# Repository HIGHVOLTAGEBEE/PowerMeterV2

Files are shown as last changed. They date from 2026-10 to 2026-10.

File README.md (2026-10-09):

# XT90 Power Meter

Precision high-current power meter with electronic fuse (eFuse) functionality, PWM dimmer and constant-current / constant-power regulation, built around an ESP32-S3 and the INA228 main measuring IC. Designed for continuous currents up to 50 A.

The device measures voltage, current, power and temperature in real time, switches the load through two parallel MOSFETs, and provides a complete web interface plus a 100 Hz JSON serial telemetry stream.

<!-- HERO IMAGE -->
<p align="center">
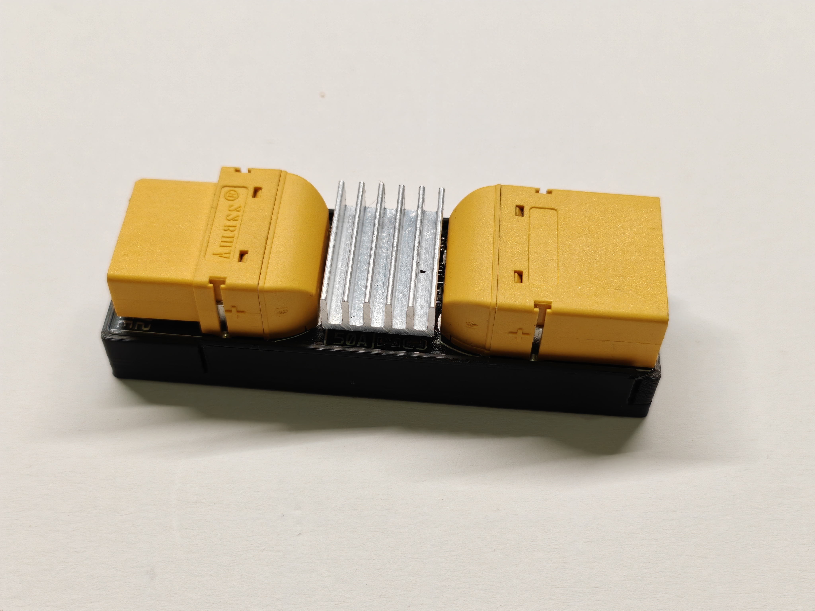
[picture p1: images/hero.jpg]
XT90 Power Meter - assembled device

</p>

---

## Table of Contents

- [Features](#features)
- [Hardware](#hardware)
- [Repository Structure](#repository-structure)
- [About the Software](#about-the-software)
- [Disclaimer](#disclaimer)
- [Getting Started](#getting-started)
- [Usage](#usage)
- [Safety](#safety)
- [Contributing](#contributing)
- [License](#license)

---

## Features

### Live Measurement

- 100 Hz sensor sampling (INA228, 4x averaging, ~550 Hz internal conversion)
- WebSocket live stream at ~77 Hz
- Voltage, current, power and die temperature
- Energy counter (Wh), uptime, peak and minimum values
- Embedded live chart with zoom controls, freeze mode and PNG export

### Electronic Fuse (eFuse)

- Limits: max current, max voltage, min voltage, max temperature
- Configurable trip delay (software time-based fuse)
- Trip report with fault reason, fault values and output runtime before the trip
- Reset via web interface, serial console, or long-press of the user/boot button

### PWM Dimmer

- 10-bit PWM output, frequency configurable from 100 Hz to 30 kHz
- Smooth gauge and live slider in the web interface
- Closed-loop regulators: optinal constant current (CC) and constant power (CP) via P-controller

### Data Logger

- CSV logging to SPIFFS, up to ~65,000 entries
- Log interval configurable from 0.1 s to 3600 s
- Every entry carries the min/peak values recorded during its interval
- Progressive browser-based Excel/CSV export with progress indicator
- Restart events are written into the log

### Calibration

- Browser-based two-step calibration wizard (reference value vs. raw value)
- Separate calibration factors for voltage and current, stored in flash

### System

- Self-hosted WiFi access point (configurable SSID/password)
- mDNS (`meter.local`) when enabled
- IIR smoothing filters for voltage and current
- Configurable status LED (brightness, on/off), boot button enable
- Default-output and auto-logging behavior on boot
- Full settings persistence in flash with CRC16 validation
- UI languages: German / English

---

## Hardware

<p align="center">
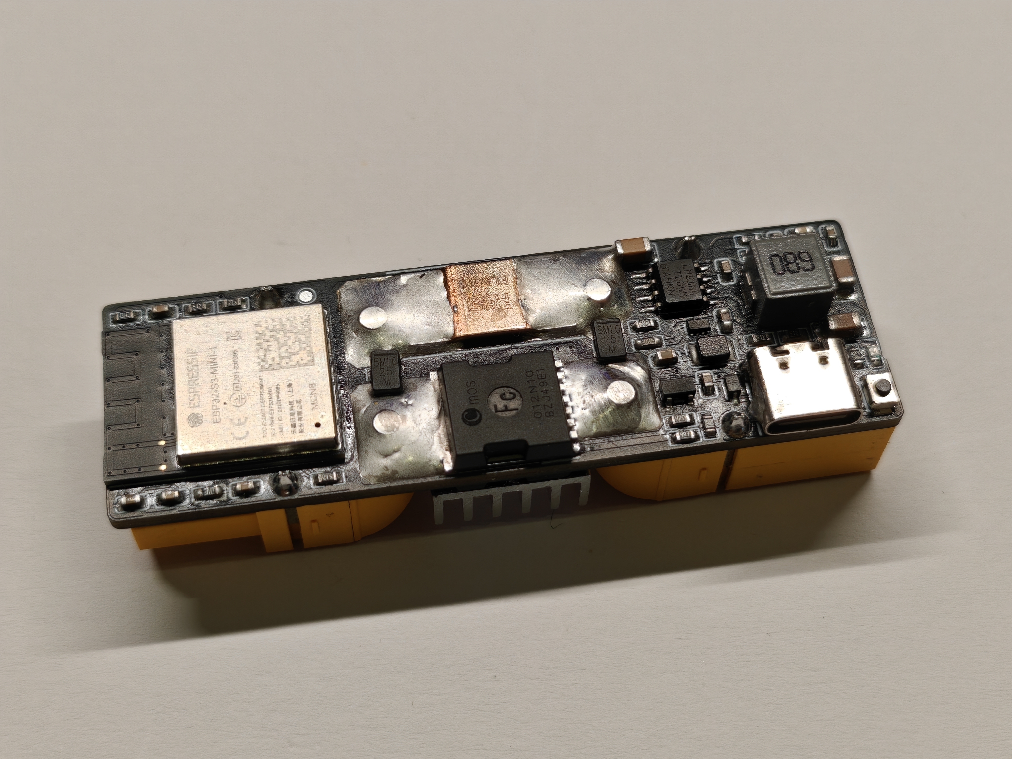
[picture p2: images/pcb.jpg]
XT90 Power Meter - assembled pcb

</p>

### Overview

| Component | Part | Function |
| --- | --- | --- |
| Microcontroller | ESP32-S3-MINI-1-N8 | WiFi AP, web server, control |
| Measurement IC  | INA228 (TI, VSSOP-10) | 20-bit shunt monitor, I2C |
| Shunt | 0.5 mOhm (5930 package) | Current sensing up to 50 A |
| Power MOSFETs | 2x CMSL012N10 (TOLL) | Load switch |
| Gate driver | UCC27517A (SOT-23-5) | MOSFET gate drive |
| Buck 12 V | LM5164 (SO-8) | Input supply from VIN |
| Buck 3.3 V | TPS629206 (SOT-583) | MCU / sensor supply |

### Pinout (ESP32-S3)

| Pin | Function |
| --- | --- |
| GPIO 0 | Boot button (active low) |
| GPIO 4 | PWM output (dimmer, 10-bit) |
| GPIO 5 | Status LED (PWM) |
| GPIO 8 / GPIO 9 | I2C SDA / SCL (INA228, 400 kHz) |
| GPIO 10 | INA228 ALERT (reserved, currently unused) |

### Schematic, PCB and Assembly

All hardware files are located in the `PCB/` folder:

| Document | File |
| --- | --- |
| Schematic | `PCB/schematic.pdf` |
| Gerber files | `PCB/gerber.zip` (RS-274X) |
| Bill of materials | `PCB/bom.xlsx` (LCSC part numbers included) |
| Pick and place | `PCB/pick.xlsx` |
| 3D model of the PCB | `PCB/3d_model.step` |

### Enclosure

<!-- CASE IMAGE -->
<p align="center">
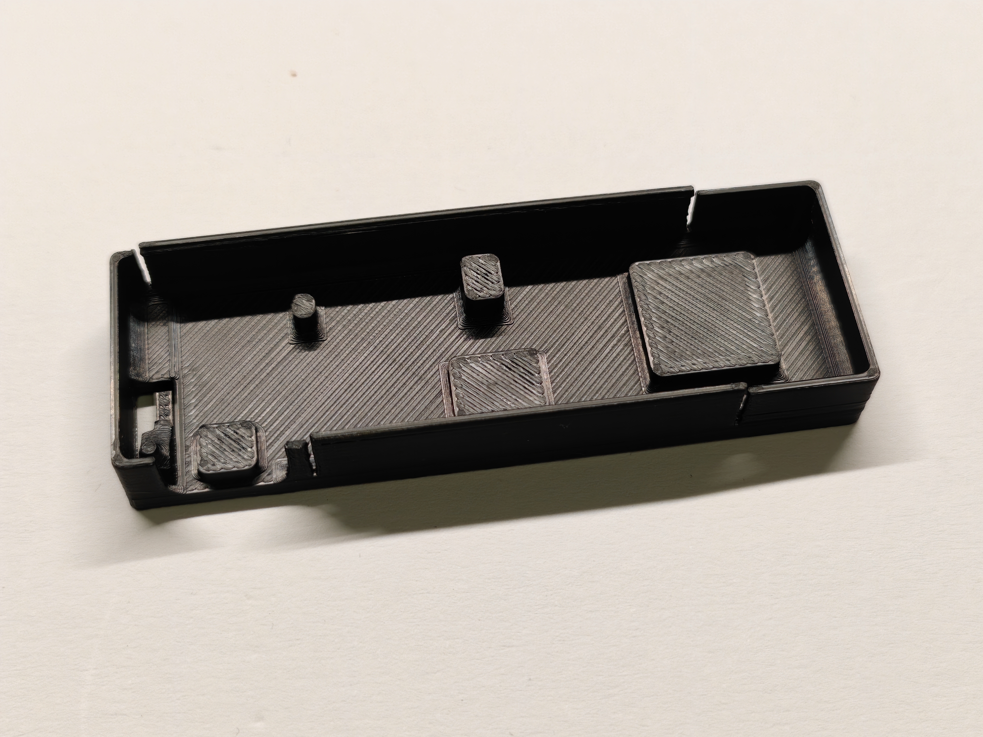
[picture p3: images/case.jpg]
XT90 Power Meter - Case

</p>

The 3D-printable enclosure is included as a 3MF file directly in the repository root. It snaps onto the PCB edge without screws and provides openings for both XT90 connectors, the USB-C port and the status LED.

| Property | Recommendation |
| --- | --- |
| File | `Case.3mf` (repository root)  |
| Material | PETG |
| Print settings | Extra Fine 0.08mm No Supports |

---

## Repository Structure

```javascript
.
├── Firmware/                   PlatformIO project (ESP32-S3)
│   ├── platformio.ini          Board config, libraries, build flags
│   ├── partitions_8mb.csv      Flash layout (3.5 MB app + 4 MB SPIFFS)
│   ├── main.cpp                Main program
│   └── include/                All firmware modules
│       ├── INA228Wrapper.*     Sensor driver, smoothing, calibration
│       ├── WebInterface.*      HTTP/WebSocket, eFuse logic, CC/CP regulator
│       ├── WebPages.*          Web UI pages
│       ├── DataLogger.*        SPIFFS CSV logging, chunked export
│       ├── Settings.*          EEPROM persistence with CRC16
│       ├── StatusLED.*         LED modes (on / breathing / eFuse blink)
│       └── SerialConsole.*     JSON command line, 100 Hz telemetry
├── PCB/
│   ├── gerber.zip              Gerber files (RS-274X)
│   ├── schematic.pdf           Schematic
│   ├── bom.xlsx                Bill of materials (LCSC part numbers)
│   ├── pick.xlsx               Pick and place data
│   └── 3d_model.step           3D model of the PCB
├── Case.3mf                    3D-printable snap-on enclosure
├── images/                     Photos and screenshots
├── LICENSE                     GNU AGPL v3
├── README.md
└── SETUP.md                    Detailed build and setup guide
```

---

## About the Software

A significant portion of the firmware was created with the assistance of generative AI tools. It works and has been tested on real hardware, but it should be seen as a solid starting point rather than a finished, peer-reviewed product.

I am not a software developer, and I am happy about every contribution. If you are a software developer and spot weak spots, structural problems or potential bugs or simply have ideas for new features, please open an issue or a pull request.

---

## Disclaimer

**This is a private hobby project.**

There is **no guarantee of functionality** - neither for the hardware nor for the firmware. Everything is provided "as is", without any warranty of any kind. I am not an electrical engineer or a professional software developer.

Use this project **entirely at your own risk**. It has been built and tested to the best of my knowledge, but it is not certified, not safety rated and not intended for any application where failure could cause damage, injury or danger - especially not for safety critical or unattended operation.

If you build and use this device, you are responsible for verifying that it works correctly in your setup and for complying with all applicable regulations.

---

## Getting Started

The firmware is a complete [PlatformIO](https://platformio.org/) project for Visual Studio Code - board settings, library dependencies and the flash partition table are all defined in `platformio.ini`, no manual library installation required.

The short version:

1. Install [Visual Studio Code](https://code.visualstudio.com/) with the [PlatformIO IDE extension](https://platformio.org/platformio-ide).
2. Open the `Firmware/` folder as a PlatformIO project and upload it to the board (Upload button in the PlatformIO toolbar or `pio run --target upload`).
3. Power the board through the XT90 input.
4. Connect to the WiFi access point (default SSID `XT90_PowerMeter`, password `12345678`).
5. Open `http://192.168.4.1` or `http://meter.local` in a browser.

Full details: [SETUP.md](SETUP.md)

---

## Usage

### Web Interface

Connect to the access point and open `http://192.168.4.1` or `http://meter.local` (with mDNS enabled).

| Page | Content |
| --- | --- |
| `/` | Live view: readings, chart, output switch |
| `/logger` | Peaks/minimums, energy, logging control, Excel export |
| `/efuse` | Limits, trip report, reset |
| `/dimmer` | Dimmer slider, CC/CP regulator, gauge |
| `/config` | WiFi, PWM, smoothing, LED, button, logger, language |
| `/calibrate` | Calibration wizard |

### Serial Console

USB-CDC at 2,000,000 baud. Continuous JSON telemetry at 100 Hz and a status frame every 5 s. Commands are sent as JSON lines, for example:

```json
{"cmd":"status"}
{"cmd":"get"}
{"cmd":"set","key":"maxCurrent","value":25}
{"cmd":"output","value":1}
{"cmd":"dimmer","value":50}
{"cmd":"dimmeren","value":1}
{"cmd":"logging","value":1}
{"cmd":"efuse","value":1}
{"cmd":"resetefuse"}
{"cmd":"log"}
{"cmd":"logclear"}
{"cmd":"help"}
```

All available setting keys are listed by `{"cmd":"help"}` and `{"cmd":"get"}`.

### Boot Button

- **Short press:** toggle output
- **Long press (> 2 s):** reset eFuse

**(Currently not very reative)**

---

## Safety

- The device is designed for high currents. At 50 A, the 0.5 mOhm shunt dissipates up to 1.25 W + Mosfet heat dissipation.
- The eFuse is a software protection function and does not replace a certified fuse.
- Respect the MOSFET voltage and current ratings and provide sufficient cooling for continuous load.
- The output MOSFETs switch on the low side. When the output is off, VOUT remains connected to VIN through the load path.

---

## Contributing

Contributions of any kind are welcome - whether it is:

- bug reports and bug fixes
- code quality and structural improvements
- ideas for new features
- documentation improvements
- hardware feedback from your own build

Please open an issue first for larger changes so we can discuss the direction.

---

## License

This project is licensed under the **GNU Affero General Public License v3.0** - see the [LICENSE](LICENSE) file for details. The hardware design files are provided for reference and manufacturing.

The firmware is distributed in the hope that it will be useful, but WITHOUT ANY WARRANTY. If you run a modified version of this firmware on a network server, the AGPL requires you to make the corresponding source code available to users interacting with it.

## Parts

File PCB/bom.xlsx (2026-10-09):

No. | Quantity | Comment | Designator | Footprint | Value | Manufacturer Part | Manufacturer | Supplier Part | Supplier
1 | 1 | 2.2uF | C1 | C1206 | 2.2uF | FS31X225K101EPG | PSA(信昌电陶) | C1021612 | LCSC
2 | 2 | 22uF | C2,C3 | C1206 | 22uF | FS31X226M160EPG | PSA(信昌电陶) | C3036083 | LCSC
3 | 1 | 3.3nF | C4 | C0603 | 3.3nF | CC0603KRX7R9BB332 | YAGEO(国巨) | C107088 | LCSC
4 | 1 | 2.2nF | C5 | C0603 | 2.2nF | FCC0603B222K500CT | FOJAN(富捷) | C5137562 | LCSC
5 | 1 | 56pF | C6 | C0603 | 56pF | 0603CG560J500NT | FH(风华) | C1676 | LCSC
6 | 5 | 100nF | C7,C11,C12,C14,C16 | C0603 | 100nF | CL10B104KB8NFNC | SAMSUNG(三星) | C346191 | LCSC
7 | 2 | 22uF | C8,C13 | C0603 | 22uF | CL10A226MQ8NRNC | SAMSUNG(三星) | C59461 | LCSC
8 | 2 | 4.7uF | C9,C17 | C0603 | 4.7uF | CL10A475KO8NNNC | SAMSUNG(三星) | C19666 | LCSC
9 | 1 | 100nF | C10 | C0603 | 100nF | CL10B104KC8NNNC | SAMSUNG(三星) | C15725 | LCSC
10 | 1 | 1uF | C15 | C0603 | 1uF | CL10B105KA8NNNC | SAMSUNG(三星) | C29936 | LCSC
11 | 1 | XT90PW-M.G.Y | CN1 | CONN-TH_XT90PW-M.G.Y |  | XT90PW-M.G.Y | AMASS(艾迈斯) | C3040689 | LCSC
12 | 1 | CUS08F30,H3F | D2 | SOD-323F_L1.7-W1.3-LS2.5-RD |  | CUS08F30,H3F | TOSHIBA(东芝) | C150183 | LCSC
13 | 1 | 68uH | L1 | IND-SMD_L7.1-W6.6_H5.0 | 68uH | PSPMAA0605H-680M-IGF | PROD(谱罗德) | C2983094 | LCSC
14 | 1 | 2.2uH | L4 | L1008 | 2.2uH | APH252012C2R2MP01 | APV(爱普微) | C42455362 | LCSC
15 | 1 | YLED0603O | LED1 | LED0603-FD |  | YLED0603O | YONGYUTAI(永裕泰) | C19273153 | LCSC
16 | 2 | CMSL012N10 | Q1,Q2 | TOLL-8_L10.4-W9.9-P1.20-LS11.7-BL_2 |  | CMSL012N10 | Cmos(广东场效应半导体) | C53310613 | LCSC
17 | 2 | 442kΩ | R1,R4 | R0603 | 442kΩ | RT0603BRD07442KL | YAGEO(国巨) | C861407 | LCSC
18 | 1 | 49.9kΩ | R2 | R0603 | 49.9kΩ | RT0603BRD0749K9L | YAGEO(国巨) | C705780 | LCSC
19 | 1 | 100kΩ | R3 | R0603 | 100kΩ | FRC0603J104 TS | FOJAN(富捷) | C2907088 | LCSC
20 | 2 | 4.7Ω | R5,R6 | R0603 | 4.7Ω | SR0603FR-7W4R7L | YAGEO(国巨) | C326830 | LCSC
21 | 3 | 10kΩ | R7,R8,R10 | R0603 | 10kΩ | FRC0603J103 TS | FOJAN(富捷) | C2930027 | LCSC
22 | 1 | 124kΩ | R9 | R0603 | 124kΩ | TC0325B1243T5F | UNI-ROYAL(厚声) | C7431036 | LCSC
23 | 6 | 5.1kΩ | R11,R12,R13,R16,R17,R18 | R0603 | 5.1kΩ | RC0603FR-075K1L | YAGEO(国巨) | C105580 | LCSC
24 | 2 | 10Ω | R14,R15 | R0603 | 10Ω | 0603WAJ0100T5E | UNI-ROYAL(厚声) | C25202 | LCSC
25 | 1 | TS-064SA-017250-D4-P | SW3 | SW-SMD_L3.0-W2.5-P3.40-LS4.0-L |  | TS-064SA-017250-D4-P | Zhongdi(众迪) | C55067267 | LCSC
26 | 1 | TP | TP2 | TESTPOINT-TH_BD3.2_1 |  | TP |  | C9900007422 | LCSC
27 | 1 | INA228AQDGSRQ1 | U1 | VSSOP-10_L3.0-W3.0-P0.50-LS4.9-BL |  | INA228AQDGSRQ1 | TI(德州仪器) | C5214669 | LCSC
28 | 1 | 0.5mΩ | U2 | R5930 | 0.5mΩ | PEWM5930DL500K9 | RESI(开步睿思) | C22446542 | LCSC
29 | 1 | XT90PW-F30.G.Y | U3 | CONN-TH_XT90PW-M |  | XT90PW-F30.G.Y | AMASS(艾迈斯) | C3040690 | LCSC
30 | 1 | LM5164DDAR | U4 | SO-8_L4.9-W3.9-P1.27-LS6.0-BL-EP |  | LM5164DDAR | TI(德州仪器) | C477928 | LCSC
31 | 1 | TPS629206DRLR | U6 | SOT-583-8_L2.1-W1.2-P0.50-LS1.6-BL |  | TPS629206DRLR | TI(德州仪器) | C5219292 | LCSC
32 | 1 | 2.4GHz | U7 | BULETM-SMD_ESP32-S3-MINI-1-N8 | 2.4GHz | ESP32-S3-MINI-1-N8 | ESPRESSIF(乐鑫) | C2913206 | LCSC
33 | 2 | VSSAF5M10-M3/H | U8,U9 | SMA_L4.3-W2.6-LS5.2-RD |  | VSSAF5M10-M3/H | VISHAY(威世) | C5241914 | LCSC
34 | 1 | UCC27517ADBVR | U10 | SOT-23-5_L2.9-W1.6-P0.95-LS2.8-BL |  | UCC27517ADBVR | TI(德州仪器) | C2653784 | LCSC
35 | 1 | TYPE-C 16PIN 2MD(073) | USB2 | USB-C-SMD_TYPE-C-16PIN-2MD-073 |  | TYPE-C 16PIN 2MD(073) | SHOU HAN(首韩) | C2765186 | LCSC

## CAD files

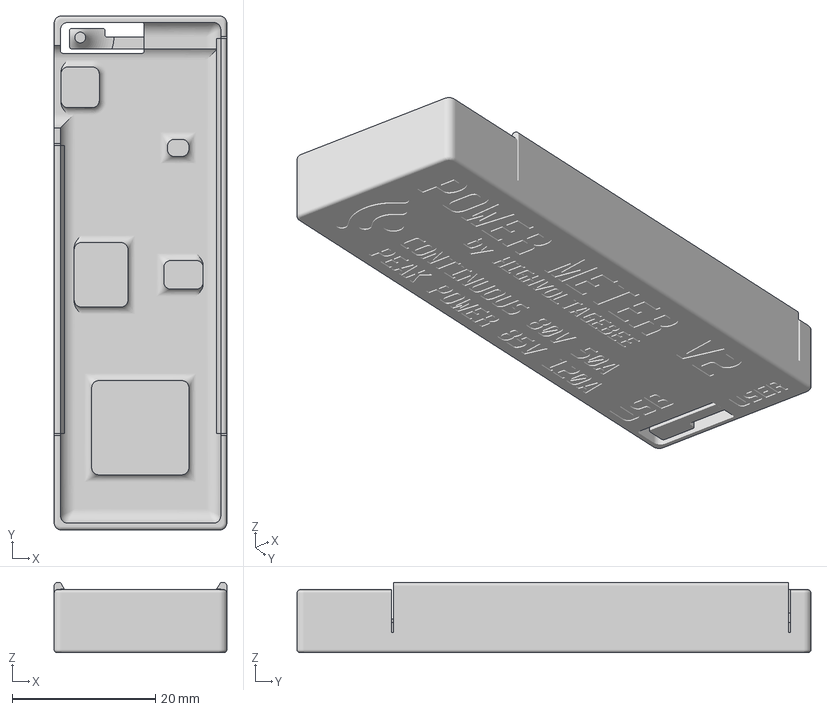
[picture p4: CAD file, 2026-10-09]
Case.3mf
24.1 x 71.7 x 9.79 mm

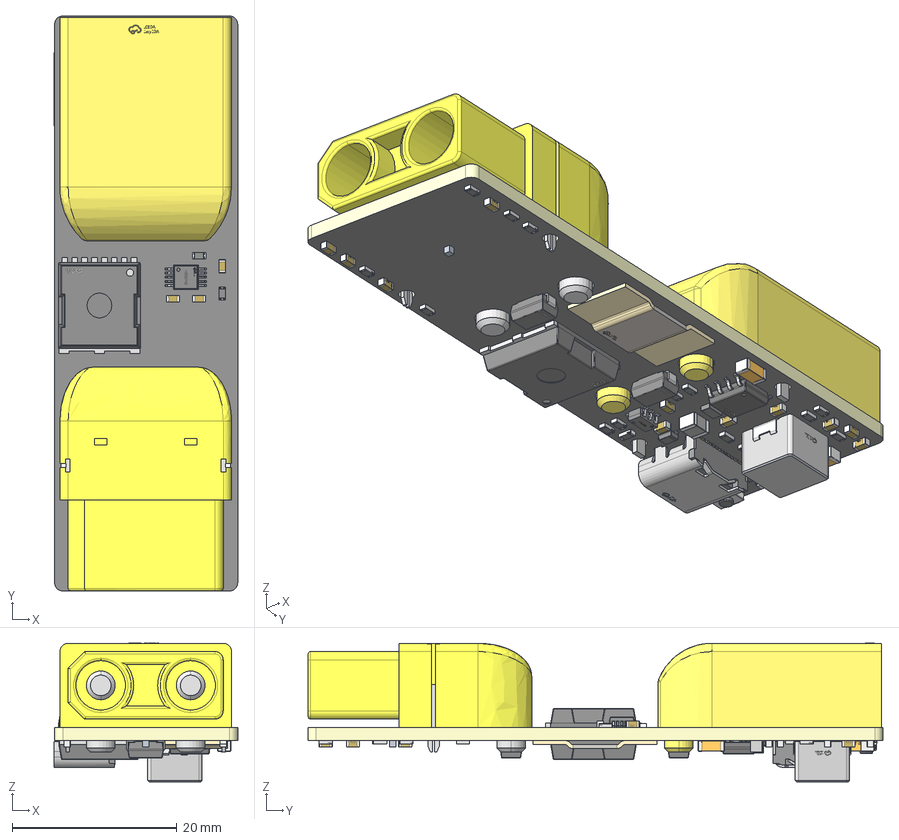
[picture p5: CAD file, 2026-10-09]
PCB/3d_model.step
22.2 x 69.7 x 16.8 mm
Board~EgBH
TopCopper~EgBH
BottomCopper~EgBH
TopSilkscreen~EgBH
BottomSilkscreen~EgBH
TopFpcStiffener~EgBH
BottomFpcStiffener~EgBH
BULETM-SMD_ESP32-S3-MINI-1-N8~BULETM-SMD_ESP32-S3-MINI-1-N8~EgBH
R5930~R5930~EgBH
L1008~L1008~EgBH
CONN-TH_XT90PW-M~CONN-TH_XT90PW-M~EgBH
R0603~R0603~EgBH x 18
CONN-TH_XT90PW-M.G.Y~CONN-TH_XT90PW-M.G.Y~EgBH
C0603~C0603_L1.6-W0.8-H0.8~EgBH x 14
IND-SMD_L7.1-W6.6_H5.0~IND-SMD_L7.1-W6.6-H5.0~EgBH
TOLL-8_L10.4-W9.9-P1.20-LS11.7-BL_2~TOLL-8_L10.4-W9.9-P1.20-LS11.7-BL_ 2~EgBH x 2
LED0603-FD~LED0603_Inf~EgBH
SOT-583-8_L2.1-W1.2-P0.50-LS1.6-BL~SOT-583-8_ L2.1-W1.2-P0.50-LS1.6-BL~EgBH
SW-SMD_L3.0-W2.5-P3.40-LS4.0-L~SW-SMD_ L3.0-W2.5-H1.6-P3.40-LS4.0-L~EgBH
SMA_L4.3-W2.6-LS5.2-RD~SMA_L4.3-W2.6-LS5.2-RD~EgBH x 2
C1206~C1206_L3.2-W1.6-H1.3~EgBH x 3
USB-C-SMD_TYPE-C-16PIN-2MD-073~USB-C-SMD_TYPE-C-6PIN-2MD-073~EgBH
SOD-323F_L1.7-W1.3-LS2.5-RD~SOD-323F_L1.7-W1.3-LS2.5-RD~EgBH
SO-8_L4.9-W3.9-P1.27-LS6.0-BL-EP~SO-8_L4.9-W3.9-H1.5-LS5.9-P1.27~EgBH
SOT-23-5_L2.9-W1.6-P0.95-LS2.8-BL~SOT-23-5_ L2.9-W1.6-P0.95-LS2.8-BL~EgBH
VSSOP-10_L3.0-W3.0-P0.50-LS4.9-BL~VSSOP-10_ L3.0-W3.0-H1.1-LS4.9-P0.50~EgBH

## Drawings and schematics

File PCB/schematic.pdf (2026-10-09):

IO48 30 IO35 31 IO36 32 IO37 33 IO38 34 IO39 35 IO40 36 IO41 37 IO42 38 TXD0 39 RXD0 40 IO45 41 GND 42 GND 43 IO46 44 EN 45 GND 46 GND 47 GND 48 GND 49 GND 50 GND 51 GND 52 GND 53 GND 54 GND 55 GND 56 GND 57 GND 58 GND 59 GND 60 GND U72.4GHz

# Mosfets

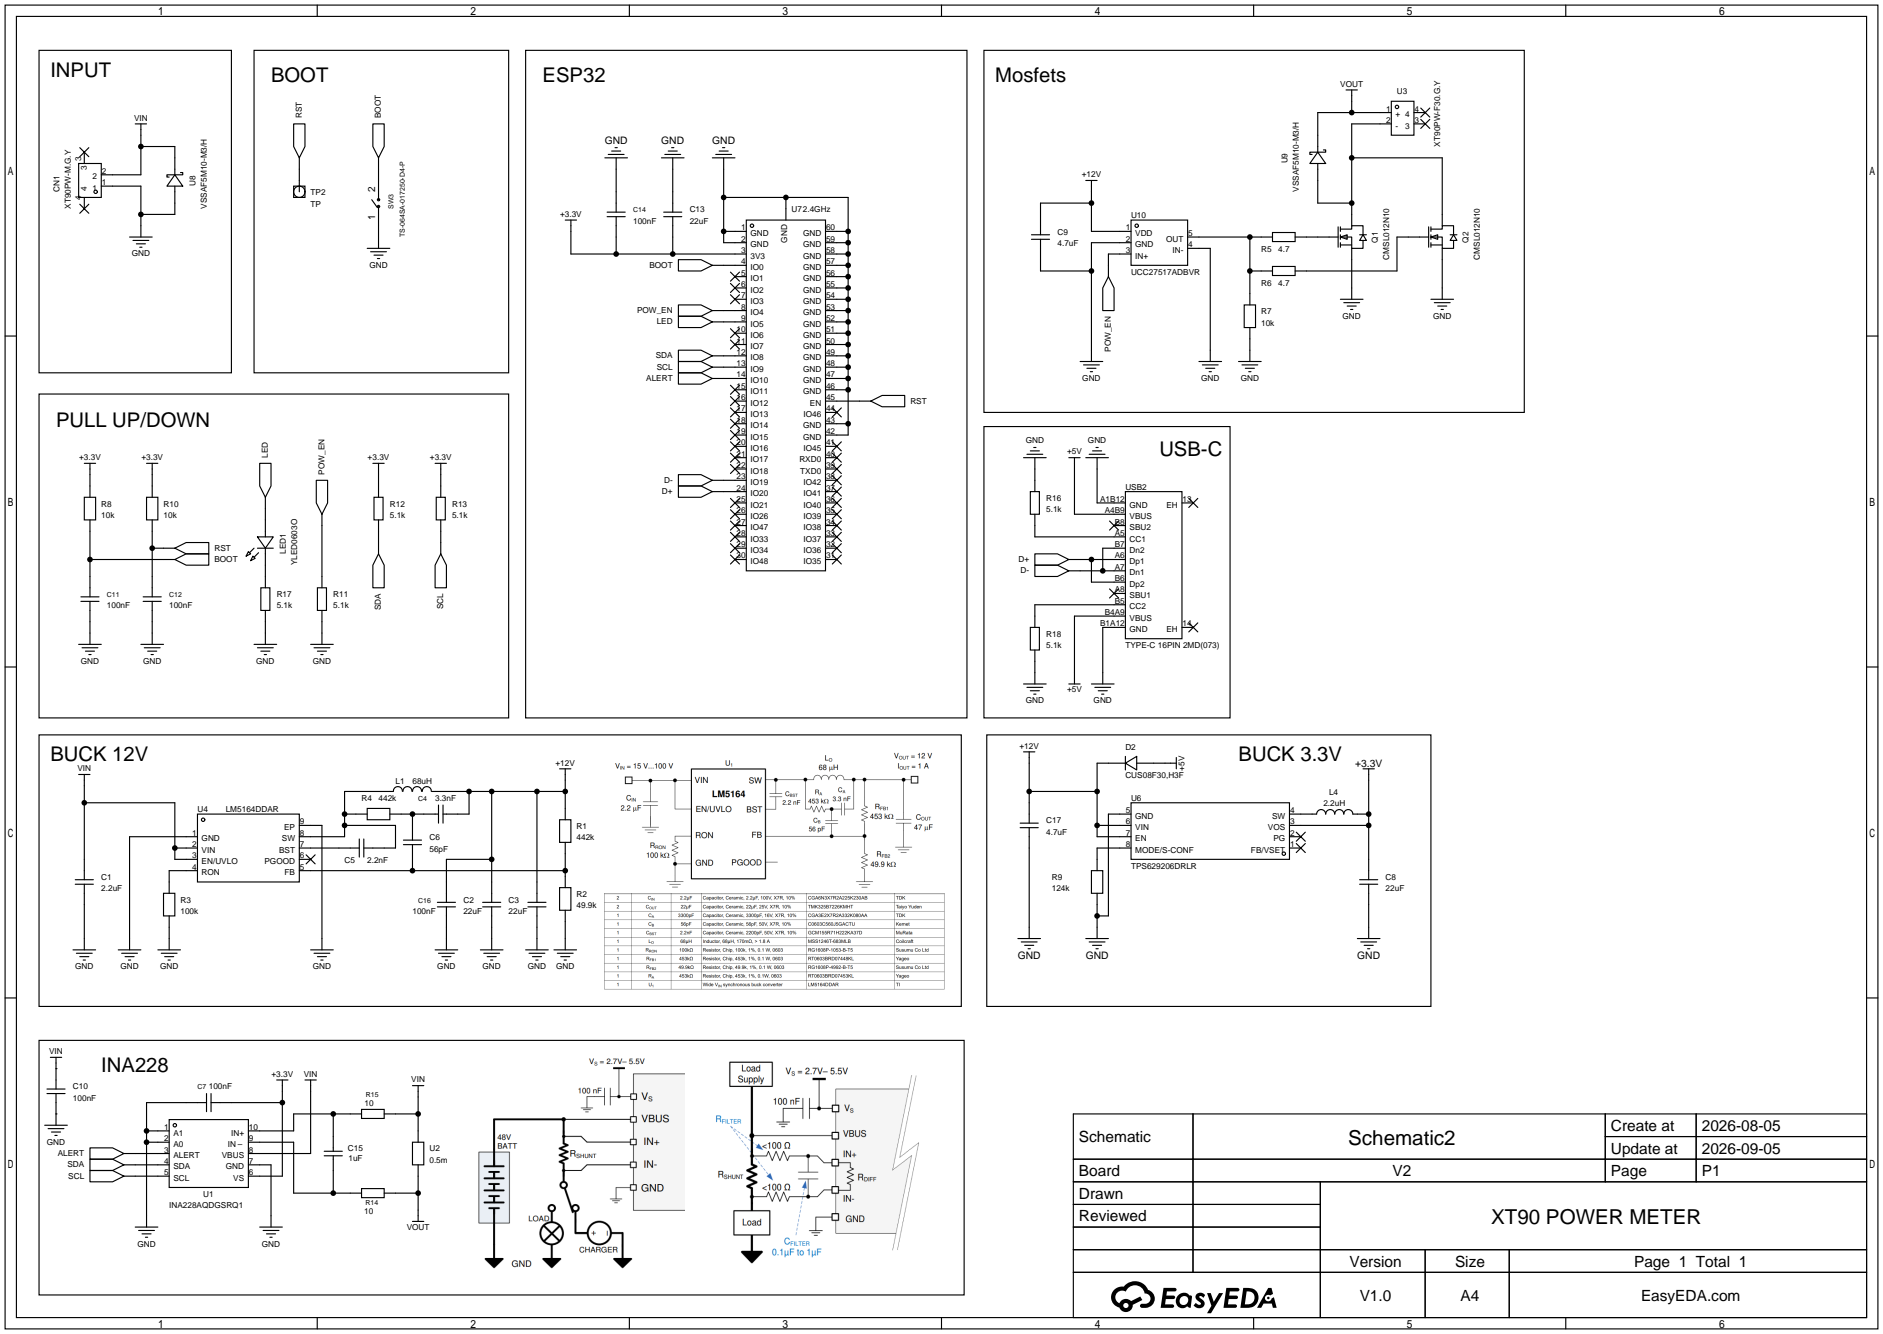
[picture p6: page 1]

Schematic | Schematic2 | Create at | 2026-08-05

Update at | 2026-09-05

Board | V2 | Page | P1
Drawn | | XT90 POWER METER
Reviewed

Version | Size | Page 1 Total 1
V1.0 | A4 | EasyEDA.com

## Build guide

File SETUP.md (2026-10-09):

# Setup Guide

Step-by-step instructions for building and setting up the XT90 Power Meter: flashing the firmware, first configuration and everyday operation.

The firmware is a **PlatformIO project for Visual Studio Code**. All board settings, dependencies and the flash partition table are defined in `platformio.ini` - you do not need to install any libraries manually.

---

## Table of Contents

- [1. Flashing the Firmware](#1-flashing-the-firmware)
- [2. First Boot](#2-first-boot)
- [3. First Configuration](#3-first-configuration)
- [4. Everyday Operation](#4-everyday-operation)
- [5. Calibration](#5-calibration)
- [6. Troubleshooting](#6-troubleshooting)

---

## 1. Flashing the Firmware

### 1.1 Requirements

- [Visual Studio Code](https://code.visualstudio.com/)
- [PlatformIO IDE extension](https://platformio.org/platformio-ide) for VS Code (when you open the project, VS Code also suggests the pioarduino fork via `Firmware/.vscode/extensions.json` - both work)
- USB-C cable
- The `Firmware/` folder of this repository

The VS Code configuration in `Firmware/.vscode/extensions.json` additionally recommends the ESP exception decoder (`Jason2866.esp-decoder`), which is very helpful for decoding crash backtraces from the serial log.

### 1.2 Project Setup

1. Open VS Code and make sure the PlatformIO IDE extension is installed.
2. `PlatformIO Home > Open Project` and select the `Firmware/` folder.
3. PlatformIO automatically reads `platformio.ini` and installs all dependencies on the first build.

> **Note on the project layout:** this project builds with `src_dir = .` and keeps all firmware modules (`INA228Wrapper`, `WebInterface`, `WebPages`, `DataLogger`, `Settings`, `StatusLED`, `SerialConsole`) in `Firmware/include/` - that is intentional, no files need to be moved. Just open the `Firmware/` folder as the project root and build.

The project is preconfigured as follows (see `platformio.ini`):

| Setting | Value |
|---|---|
| Platform | `espressif32` |
| Board | `esp32-s3-devkitc-1` |
| Framework | Arduino |
| CPU frequency | 240 MHz |
| Flash | 8 MB, QIO mode, 80 MHz |
| Partition table | `partitions_8mb.csv` (3.5 MB app + 4 MB SPIFFS for the data logger) |
| USB CDC on boot | Enabled (serial console over USB) |
| Libraries | `mathieucarbou/ESPAsyncWebServer@^3.6.0`, `mathieucarbou/AsyncTCP@^3.3.2`, `robtillaart/INA228@^0.4.0` |
| Monitor speed | 2,000,000 baud |

### 1.3 Build and Upload

1. Connect the board via USB-C.
2. Click the **Build** (checkmark) and then the **Upload** (arrow) button in the PlatformIO toolbar at the bottom of VS Code.

Or via the command line:

```bash
cd Firmware
pio run                 # build
pio run --target upload # build and flash
```

If the upload does not start automatically, hold the boot button, re-plug the board (or press reset), and release the boot button to enter download mode.

> **Note:** The serial console runs at **2,000,000 baud**. `monitor_speed` is already set in `platformio.ini`, so `pio device monitor` (or the **Monitor** button in VS Code) opens the terminal at the correct rate.

---

## 2. First Boot

On first boot (or after a settings reset) the device:

1. Initializes the INA228 sensor (I2C, 400 kHz).
2. Mounts SPIFFS and counts existing log entries.
3. Starts the WiFi access point.
4. Restores all settings from EEPROM (falls back to defaults if invalid).

Default access point credentials:

| Parameter | Default |
|---|---|
| SSID | `XT90_PowerMeter` |
| Password | `12345678` |
| IP address | `192.168.4.1` |
| mDNS | `meter.local` (if enabled) |

The serial console prints a boot log including the AP IP address, the sensor status and the current settings.

---

## 3. First Configuration

Open the web interface and go to **Settings** (`/config`):

1. **WLAN:** change the AP SSID and password.
2. **System:** set the PWM frequency for your load (100 Hz - 30 kHz), default output state and language.
3. **Smoothing:** adjust the voltage/current IIR smoothing if the readings are too noisy or too slow (0 % = no smoothing).
4. **LED / Button:** configure the status LED brightness and whether the boot button is active.
5. **Logger:** set the log interval and auto-start behavior.

Press **Save** - all settings are stored in EEPROM with CRC validation and survive power cycles.

### Recommended eFuse Defaults

On the **eFuse** page, a sensible starting point is:

| Limit | Suggested value |
|---|---|
| Max current | 5 A below your continuous load rating |
| Max voltage | 10 % above your nominal input voltage |
| Min voltage | 10 % below your nominal input voltage |
| Max temperature | 80 °C |
| Trip delay | 0.5 - 1.0 s (longer for inrush, shorter for hard protection) |

Enable the eFuse with the **eFUSE ON** button. When a limit is exceeded for the configured delay, the output switches off and a trip report is displayed.

---

## 4. Everyday Operation

### Switching the Output

- Web interface (Live / eFuse / Dimmer page): the **OUTPUT** button.
- Boot button: short press toggles the output.
- Serial console: `{"cmd":"output","value":1}`.

### Dimmer and Regulators

1. Enable the dimmer on the **Dimmer** page.
2. Move the slider (throttled automatically to protect the WebSocket link), or
3. Enable a regulator:
   - **CC (constant current):** set a current in A; the P-controller adjusts the PWM duty cycle to hold it.
   - **CP (constant power):** set a power in W; the controller holds the power constant.

Regulators only run while the dimmer and the output are both enabled.

### Logging and Export

1. Enable logging on the **Logger** page.
2. Choose an interval (0.1 - 3600 s).
3. Export with **Excel Export** - the browser downloads the full log as an `.xls` file (HTML table format) with a progress dialog.
4. **Clear Log** wipes the log file.

### Status LED

| LED behavior | Meaning |
|---|---|
| Breathing (slow) | Output off, device idle |
| Solid on | Output on |
| Fast blinking | eFuse tripped |

---

## 5. Calibration

Use the calibration wizard at `/calibrate` for best accuracy:

1. Choose the channel (voltage or current).
2. Enter the reference value measured with a trusted instrument.
3. Apply a stable source and start the 3-second averaged measurement.
4. The wizard computes the calibration factor (reference / raw) and stores it in EEPROM.

Repeat for the second channel. Each factor is validated on boot and reset to 1.0 if it is out of range.

---

## 6. Troubleshooting

| Symptom | Possible cause | Solution |
|---|---|---|
| No AP visible | Wrong flash settings | Check that `partitions_8mb.csv` is used and USB CDC on boot is enabled (both set in `platformio.ini`), re-flash |
| Build fails on first try | Dependencies not downloaded yet | Run the build again - PlatformIO installs the libraries on first build |
| Web UI not loading | Browser cache | Hard reload (Ctrl+F5) |
| Sensor shows 0 / "INA228 not found" | I2C wiring, sensor damage | Check SDA/SCL (GPIO 8/9), 3.3 V supply |
| Readings noisy | Smoothing too low | Increase smoothing on the Settings page |
| Readings offset | Missing calibration | Run the calibration wizard |
| Output does not switch on | eFuse tripped / min voltage set | Check trip report on the eFuse page, reset eFuse |
| Logger full | SPIFFS capacity reached | Export and clear the log |
| Serial console garbled | Wrong baud rate | Use `pio device monitor` (2,000,000 baud is set in `platformio.ini`) |

If the issue persists, please open an issue with the serial boot log attached.

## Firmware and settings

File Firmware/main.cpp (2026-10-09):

#include "INA228Wrapper.h"
#include "DataLogger.h"
#include "WebInterface.h"
#include "Settings.h"
#include "StatusLED.h"
#include "SerialConsole.h"

#define BUTTON_PIN 0 // Boot Button, LOW aktiv
#define BTN_DEBOUNCE_MS 30
#define BTN_LONGPRESS_MS 2000

INA228Wrapper ina228;
DataLogger dataLogger;
Settings settings;
StatusLED statusLed;
WebInterface webInterface(&ina228, &dataLogger, &settings, &statusLed);
SerialConsole serialConsole;

uint32_t lastSensorRead = 0;

bool btnLastRaw = HIGH;
bool btnStableState = HIGH;
uint32_t btnLastChange = 0;
uint32_t btnPressStart = 0;
bool btnLongPressFired = false;

// Hinweis: Webserver/Broadcast laufen bewusst im Arduino-Haupt-Loop (Core 1),
// nicht in einem eigenen Core-0-Task. Der async_tcp-Task von AsyncTCP laeuft
// auf Core 0 - ein zweiter Task auf demselben Kern, der _ws.textAll()/
// cleanupClients() aufruft, wurde mitten in der Clientlisten-Iteration
// unterbrochen und hat den Webserver zum Absturz gebracht.
// updateSafety() (eFuse, Energie, Graph, Regler) bleibt als eigene Methode,
// damit die Trennung bei Bedarf leicht wieder aktiviert werden kann.

void setup()
{
  Serial.begin(2000000);
  delay(100);
  Serial.println("\nXT90 Power Meter starting...");

  settings.begin();

  if (!ina228.begin(8, 9))
  {
    Serial.println("INA228 not found!");
  }
  else
  {
    Serial.println("INA228 connected (400kHz I2C)");
    ina228.resetAccumulators();
    ina228.printDebug();
  }

  if (!dataLogger.begin())
  {
    Serial.println("SPIFFS failed!");
  }
  else
  {
    Serial.printf("SPIFFS ready, %u log entries\n", dataLogger.getEntryCount());
  }

  dataLogger.setEnabled(settings.data.loggingEnabled);
  dataLogger.setIntervalSec(settings.data.logIntervalSec);
  if (settings.data.loggingEnabled)
  {
    dataLogger.logEvent("RESTART"); // Neustart im Log vermerken
  }

  statusLed.begin(settings.data.ledEnabled, settings.data.ledMaxBrightness);

  pinMode(BUTTON_PIN, INPUT_PULLUP);

  webInterface.begin();

  serialConsole.begin(&ina228, &dataLogger, &settings, &statusLed, &webInterface);

  if (settings.data.defaultOutputOn)
  {
    webInterface.setOutputEnabled(true);
  }

  Serial.print("AP SSID: ");
  Serial.println(settings.data.apSSID);
  Serial.print("AP IP: ");
  Serial.println(WiFi.softAPIP());
  Serial.print("Default Output: ");
  Serial.println(settings.data.defaultOutputOn ? "ON" : "OFF");
  Serial.print("Dimmer: ");
  Serial.print(settings.data.dimmerPercent);
  Serial.println("%");
  Serial.print("Serial Telemetry: 2000000 Baud, 100 Hz");
}

void handleButton()
{
  if (!settings.data.buttonEnabled)
    return;

  bool raw = digitalRead(BUTTON_PIN); // LOW = gedrueckt
  uint32_t now = millis();

  if (raw != btnLastRaw)
  {
    btnLastChange = now;
    btnLastRaw = raw;
  }

  if (now - btnLastChange < BTN_DEBOUNCE_MS)
    return;

  if (raw != btnStableState)
  {
    btnStableState = raw;
    if (raw == LOW)
    {
      // Taste gedrueckt
      btnPressStart = now;
      btnLongPressFired = false;
    }
    else
    {
      // Taste losgelassen
      if (!btnLongPressFired && now - btnPressStart < BTN_LONGPRESS_MS)
      {
        webInterface.toggleOutput();
        Serial.printf("{\"t\":\"btn\",\"out\":%d}\n", webInterface.getOutputEnabled() ? 1 : 0);
      }
    }
  }

  if (btnStableState == LOW && !btnLongPressFired && now - btnPressStart >= BTN_LONGPRESS_MS)
  {
    btnLongPressFired = true;
    webInterface.resetEFuse();
    Serial.println("{\"t\":\"btn\",\"efreset\":1}");
  }
}

void loop()
{
  uint32_t now = micros();

  // Auslesung zeitgesteuert: 100 Hz (Alert-Pin deaktiviert)
  if (now - lastSensorRead >= 10000)
  {
    lastSensorRead = now;
    ina228.readAll();
  }

  webInterface.updateWeb();
  webInterface.updateSafety();
  serialConsole.update();

  bool outputState = webInterface.getOutputEnabled() && !webInterface.getEFuseTriggered();
  statusLed.update(outputState, webInterface.getEFuseTriggered());

  handleButton();

  dataLogger.log(
      ina228.getVoltage(), ina228.getCurrent(), ina228.getPower(),
      webInterface.getEnergyAccum());
}

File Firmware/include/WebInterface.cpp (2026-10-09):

#include "WebInterface.h"
#include "WebPages.h"
#include <ESPmDNS.h>

WebInterface::WebInterface(INA228Wrapper *sensor, DataLogger *logger, Settings *settings, StatusLED *led)
    : _sensor(sensor), _logger(logger), _settings(settings), _led(led),
      _server(80), _ws("/ws"),
      _outputEnabled(false), _eFuseTriggered(false), _dimmerEnabled(false), _mdnsStarted(false),
      _lastBroadcast(0), _lastGraphUpdate(0),
      _graphIndex(0), _graphCount(0),
      _peakCurrent(0), _peakVoltage(0), _minCurrent(999), _minVoltage(999),
      _energyAccum(0), _startTime(0), _lastEnergyTime(0), _lastRegTime(0),
      _faultStartTime(0), _outputOnTime(0), _tripTime(0),
      _faultCurrent(0), _faultVoltage(0), _faultTemp(0), _faultReason("")
{
  memset(_graphData, 0, sizeof(_graphData));
  memset(_graphDataV, 0, sizeof(_graphDataV));
  memset(_graphDataW, 0, sizeof(_graphDataW));
}

void WebInterface::setOutputEnabled(bool en)
{
  _outputEnabled = en;
  applyDimmer();
}

void WebInterface::applyDimmer()
{
  if (_outputEnabled && !_eFuseTriggered && _dimmerEnabled)
  {
    int duty = (_settings->data.dimmerPercent * 1023) / 100;
    ledcWrite(PWM_PIN, duty);
  }
  else if (_outputEnabled && !_eFuseTriggered && !_dimmerEnabled)
  {
    ledcWrite(PWM_PIN, 1023);
  }
  else
  {
    ledcWrite(PWM_PIN, 0);
  }
}

void WebInterface::applyMdns()
{
  if (_settings->data.mdnsEnabled && !_mdnsStarted)
  {
    if (MDNS.begin("meter"))
    {
      MDNS.addService("http", "tcp", 80);
      _mdnsStarted = true;
    }
  }
  else if (!_settings->data.mdnsEnabled && _mdnsStarted)
  {
    MDNS.end();
    _mdnsStarted = false;
  }
}

void WebInterface::applyHardwareSettings()
{
  _sensor->setSmoothing(_settings->data.vSmooth, _settings->data.cSmooth);
  _sensor->setCalibration(_settings->data.calVScale, _settings->data.calVOffset,
                          _settings->data.calAScale, _settings->data.calAOffset);
  _led->setEnabled(_settings->data.ledEnabled);
  _led->setMaxBrightness(_settings->data.ledMaxBrightness);
  _logger->setIntervalSec(_settings->data.logIntervalSec);
}

void WebInterface::begin()
{
  WiFi.mode(WIFI_AP);
  WiFi.softAP(_settings->data.apSSID, _settings->data.apPassword);
  applyMdns();

  ledcAttach(PWM_PIN, _settings->data.pwmFrequency, PWM_RES);

  _outputEnabled = _settings->data.defaultOutputOn;
  _dimmerEnabled = false;
  applyDimmer();
  applyHardwareSettings();

  _ws.onEvent([this](AsyncWebSocket *server, AsyncWebSocketClient *client, AwsEventType type, void *arg, uint8_t *data, size_t len)
              { onWsEvent(server, client, type, arg, data, len); });
  _server.addHandler(&_ws);

  _server.on("/", HTTP_GET, [this](AsyncWebServerRequest *request)
             { request->send(200, "text/html", webPageLive()); });

  _server.on("/logger", HTTP_GET, [this](AsyncWebServerRequest *request)
             { request->send(200, "text/html", webPageLogger()); });

  _server.on("/efuse", HTTP_GET, [this](AsyncWebServerRequest *request)
             { request->send(200, "text/html", webPageEfuse()); });

  _server.on("/dimmer", HTTP_GET, [this](AsyncWebServerRequest *request)
             { request->send(200, "text/html", webPageDimmer()); });

  _server.on("/config", HTTP_GET, [this](AsyncWebServerRequest *request)
             { request->send(200, "text/html", webPageSettings()); });

  _server.on("/graph", HTTP_GET, [this](AsyncWebServerRequest *request)
             {
    int points = 100;
    if (request->hasParam("p")) {
      points = request->getParam("p")->value().toInt();
    }
    request->send(200, "text/plain", generateGraphData(points)); });

  _server.on("/loginfo", HTTP_GET, [this](AsyncWebServerRequest *request)
             {
    uint32_t total = _logger->getTotalBytes();
    uint32_t used = _logger->getUsedBytes();
    uint32_t pct = total > 0 ? (used * 100) / total : 0;
    String json = "{\"entries\":" + String(_logger->getEntryCount()) +
                  ",\"usedKB\":" + String(used / 1024) +
                  ",\"totalKB\":" + String(total / 1024) +
                  ",\"freeKB\":" + String((total - used) / 1024) +
                  ",\"pct\":" + String(pct) + "}";
    request->send(200, "application/json", json); });

  _server.on("/logchunk", HTTP_GET, [this](AsyncWebServerRequest *request)
             {
    uint32_t offset = 0;
    if (request->hasParam("o")) offset = request->getParam("o")->value().toInt();
    int count = 100;
    if (request->hasParam("c")) count = constrain(request->getParam("c")->value().toInt(), 1, 500);
    int32_t nextOffset;
    bool done;
    String data = _logger->readLogChunk(offset, count, &nextOffset, &done);
    String resp = "#OFF:" + String(nextOffset) + "," + (done ? "1" : "0") + "\n" + data;
    request->send(200, "text/plain", resp); });

  _server.on("/logclear", HTTP_POST, [this](AsyncWebServerRequest *request)
             {
    _logger->clear();
    request->send(200, "text/plain", "OK"); });

  _server.on("/resetefuse", HTTP_POST, [this](AsyncWebServerRequest *request)
             {
    _eFuseTriggered = false; _faultStartTime = 0; _outputOnTime = 0; _tripTime = 0;
    _faultReason = ""; _faultCurrent = 0; _faultVoltage = 0; _faultTemp = 0;
    _peakCurrent = 0; _peakVoltage = 0; _minCurrent = 999; _minVoltage = 999;
    _energyAccum = 0;
    request->send(200, "text/plain", "OK"); });
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
